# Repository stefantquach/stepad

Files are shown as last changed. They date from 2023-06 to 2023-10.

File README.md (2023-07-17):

# stepad

# Case notes:
Different material thicknesses (in stack order)
* plate thickness: White Delrin 0.06in (1.524mm)
* open1: White Acrylic 0.12in (3.05mm)
* open2: White Acrylic 0.18in (4.57mm)
* open3: White Acrylic 0.12in (3.05mm)
* bottom: White Acrylic 0.12in (3.05mm). This could be variable thickness and material.

# Build notes:
* Diode direction is reversed.

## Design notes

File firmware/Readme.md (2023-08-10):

# Stepad Firmware

### Notes:
* 1kHz interrupt for when ADC completes all samples and DMA transfer is complete. This needs to be larger than 4 samples for future use. Use DMA to trigger IRQ.
* During 1kHz interrupt, send keyboard report for the analog keys that were pressed during that poll.
* Maybe also include the digital keys in the 1kHz loop since they should be pretty fast.

* If DSP is needed, maybe have one CPU dedicated to sampling the ADC and then doing the DSP. Probably dont do this since this doesnt scale well with number of switches.

- USB HID report generator needs to be at user level. 
- CPU1 user level needs as light as possible.
- CPU1 User level runs at 1kHz delta timed loop.

- CPU1 ADC samples ADCS at n times the USB polling rate where n is the number of samples for debouncing

- CPU2 handles LED stuff

Switch 0: Top: 2036     Bottom:1513
Switch 1: Top: 2091     Bottom:1464
Switch 2: Top: 2012     Bottom:1311
Switch 3: Top: 2052     Bottom:1478

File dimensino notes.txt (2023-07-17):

14mm x 14mm hole
19.05

24.3

10mm from bottom plate to top of bottom case

PCB dimensions
35.05mm x 111.25mm

usb center to right edge: 55.675mm
usb center to left edge:  55.575mm

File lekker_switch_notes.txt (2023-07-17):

using AH49E hall sensor with VCC=3.3V

Sensor max voltage 2.3V @ 1000 G
Sensor min voltage 1.0V @ -1000 G

1.28V (bottom) to 1.56V (rest)
1.28V --> -569.231 Gauss
1.56V --> -138.462 Gauss

1.63 (rest) 1.31 (bottom)
1.31V --> -523.077 Gauss
1.63V --> -30.769 Gauss

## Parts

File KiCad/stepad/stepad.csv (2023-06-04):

Source: | C:\Users\stefa\Documents\Projects\stepad\KiCad\stepad\stepad.kicad_sch
Date: | 6/3/2023 11:15:48 AM
Tool: | Eeschema (6.0.0)
Generator: | C:\Users\stefa\Documents\Projects\stepad\KiCad\stepad\scripts/bom_generator.py
Component Count: | 69
Qnty | Product | Description | Value | Schematic | Note
16 | C0603C104M4RAC7411 | Unpolarized capacitor | 0.1u | C1, C2, C3, C4, C5, C10, C11, C12, C13, C14, C15, C16, C17, C18, C21, C24,
4 |  | Unpolarized capacitor | DNI | C6, C7, C8, C9,
2 | CL10B104KA8NNNC | Unpolarized capacitor | 1u | C19, C20,
2 | C0603C270J3GAC7867 | Unpolarized capacitor | 27p | C22, C23,
4 | QBLP677R-RGB | RGB LED, blue/green/red/anode | QBLP677R-RGB | D1, D2, D3, D4,
2 | 1N4148W-13-F | 75V 0.15A Fast Switching Diode, SOD-123 | 1N4148W | D5, D6,
1 | USB4105-GF-A |  | TYPE-C-31-M12_13_EDITED | J1,
1 |  | Generic connector, single row, 01x03, script generated (kicad-library-utils/schlib/autogen/connector/) | Conn_01x03 | J2,
2 |  |  | MX-NoLED | MX1, MX2,
4 | RC0603FR-070RL | Resistor, US symbol | 0 | R1, R2, R3, R4,
3 | RC0603JR-07300RL | Resistor, US symbol | 300 | R5, R6, R7,
2 | RC0603FR-1327RL | Resistor, US symbol | 27 | R8, R9,
3 |  | Resistor, US symbol | DNI | R10, R12, R13,
2 | RNCP0603FTD10K0 | Resistor, US symbol | 10k | R11, R16,
2 | RC0603FR-135K1L | Resistor, US symbol | 5.1k | R14, R15,
4 |  |  | MX_Lekker | SW1, SW2, SW3, SW4,
2 | MSLPT5252AG3TR | Push button switch, generic, two pins | SW_Push | SW5, SW6,
4 |  | test point | TestPoint | TP1, TP2, TP3, TP4,
4 | AH49ENTR-G1 |  | AH49-E | U1, U2, U3, U4,
1 | AZ1117IH-3.3TRG1 | 1A Low drop-out regulator, Fixed Output 3.3V, SOT-223 | NCP1117-3.3_SOT223 | U5,
1 | W25Q32JVSS | 32Mb Serial Flash Memory, Standard/Dual/Quad SPI, SOIC-8 | W25Q32JVSS | U6,
1 | SC0914(13) |  | RP2040 | U7,
1 | 82400102 | Low Capacitance TVS Diode Array, 2 Channels, SOT-23-6 | WE-TVS-82400102 | U8,
1 | RH100-12.000-18-2030-TR | Four pin crystal, GND on pins 2 and 4 | Crystal_GND24 | Y1,

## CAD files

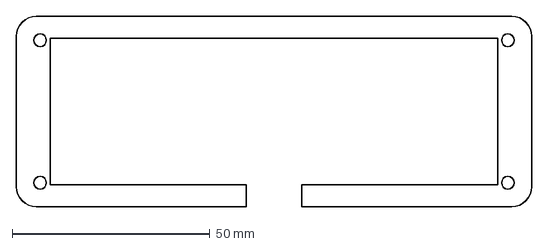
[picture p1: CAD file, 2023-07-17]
case/open2_1.dxf
130.3 x 48.1 mm

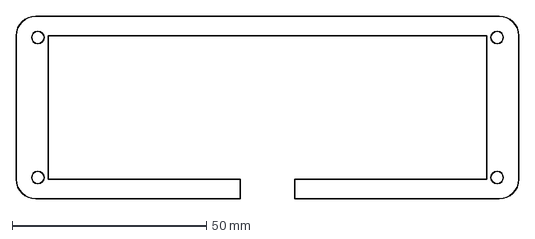
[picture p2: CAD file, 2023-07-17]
case/open2.dxf
129.3 x 47.0 mm

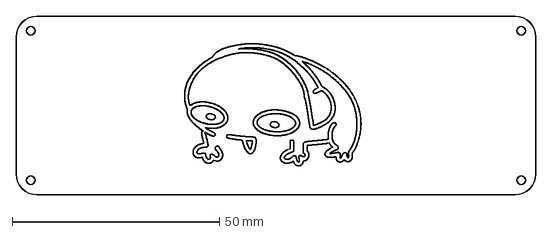
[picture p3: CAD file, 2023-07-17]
case/bottom.dxf
125.2 x 43.1 mm

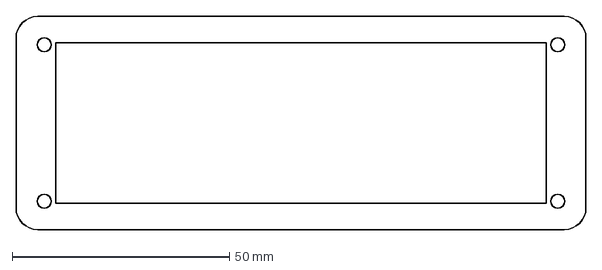
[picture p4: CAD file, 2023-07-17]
case/open3.dxf
131.2 x 49.1 mm

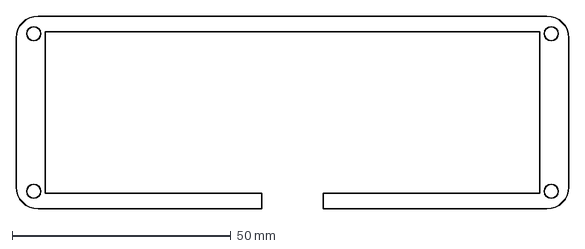
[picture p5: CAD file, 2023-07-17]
case/open1.dxf
126.3 x 44.1 mm

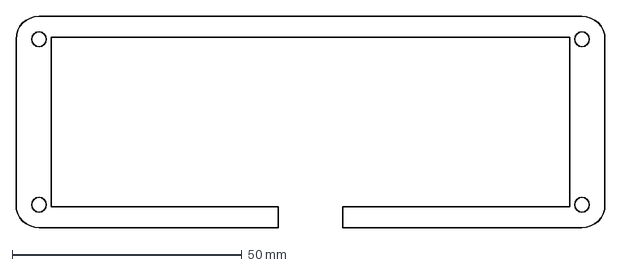
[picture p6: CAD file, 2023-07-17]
case/open1_2.dxf
128.3 x 46.1 mm

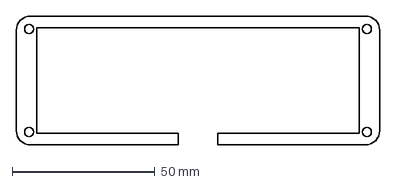
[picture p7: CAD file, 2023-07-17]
case/open1_1.dxf
127.3 x 45.0 mm

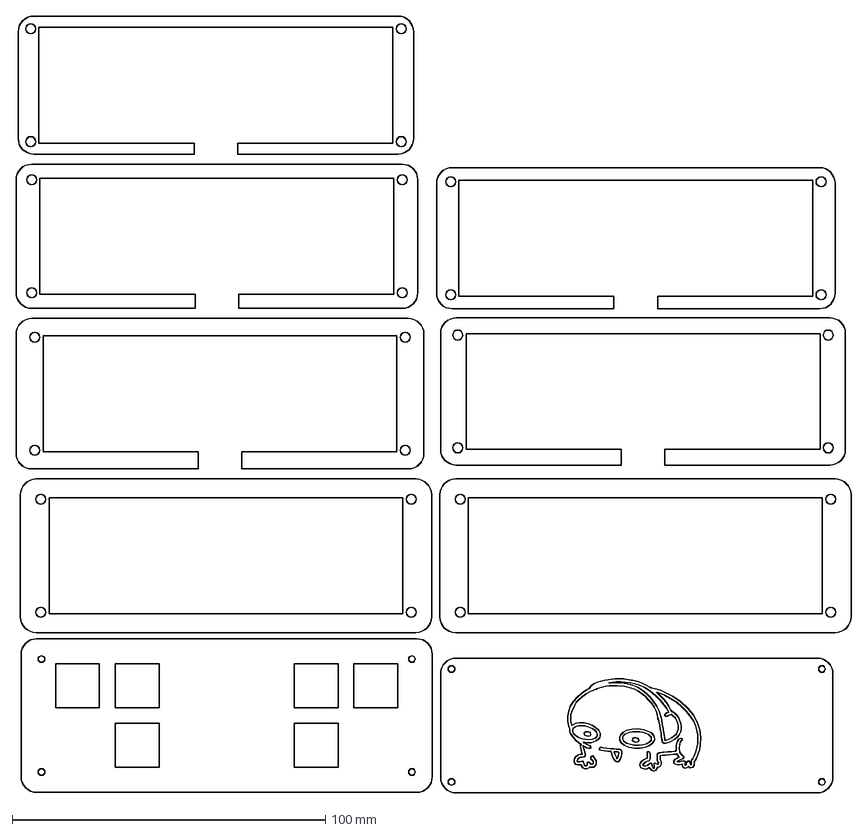
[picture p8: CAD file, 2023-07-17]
case/combined3.dxf
266.6 x 248.0 mm

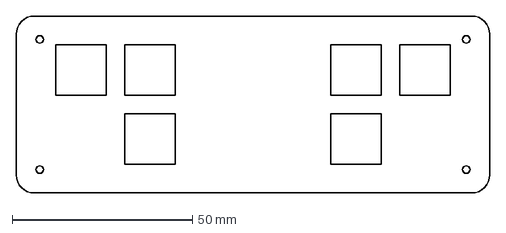
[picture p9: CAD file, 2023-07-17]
case/plate.dxf
131.2 x 49.1 mm

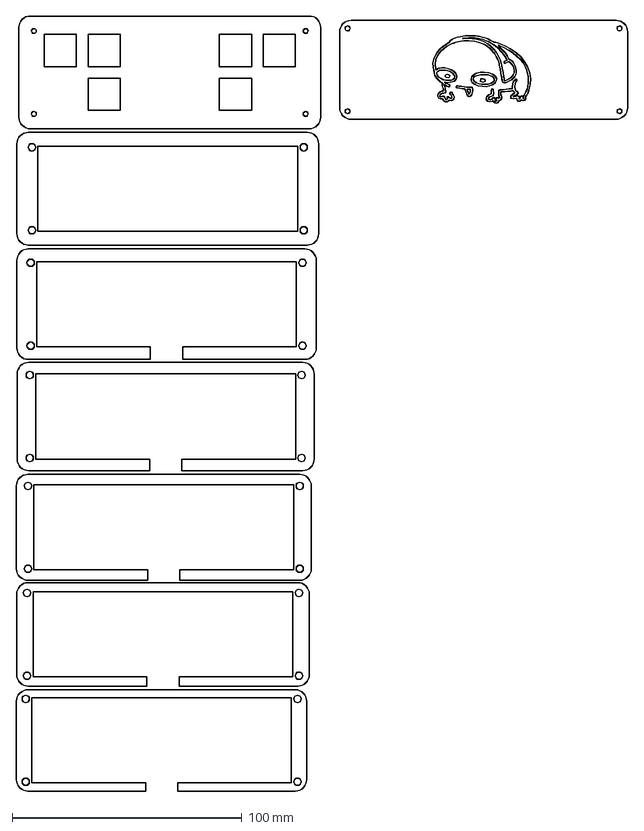
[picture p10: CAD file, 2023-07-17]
case/combined2.dxf
265.8 x 337.1 mm

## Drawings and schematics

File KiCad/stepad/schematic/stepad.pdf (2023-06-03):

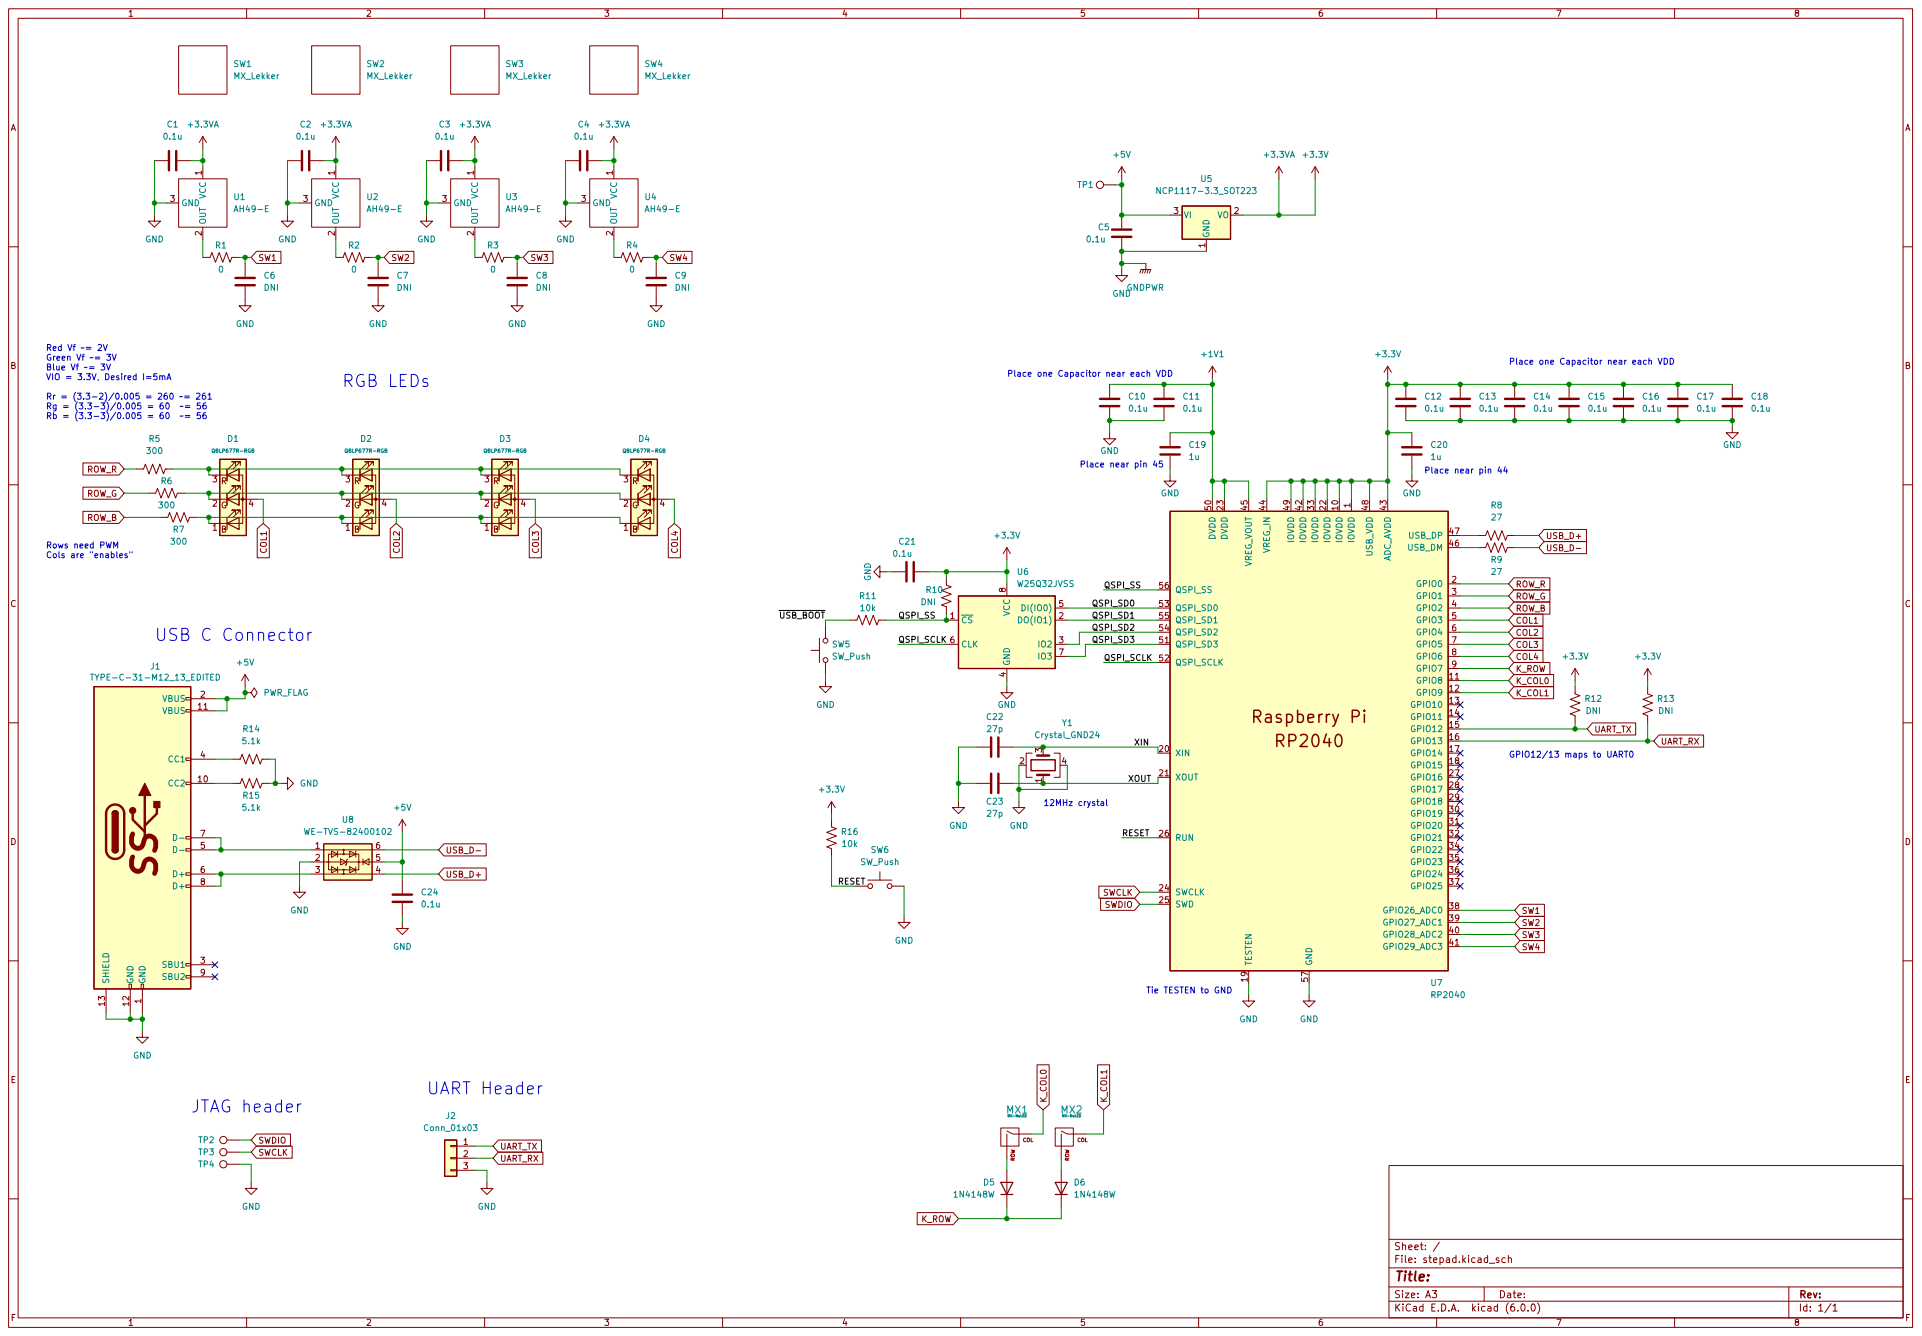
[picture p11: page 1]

2 GND 3 U4AH49-E GND GND SS GND

Cols are "enables" Red Vf ~= 2V Green Vf ~= 3V

Place one Capacitor near each VDD

1 IOVDD 10 GPIO8 11 GPIO9 12 GPIO10 13 GPIO11 14 GPIO12 15 GPIO13 16 GPIO14 17 GPIO15 18 TESTEN 19 GPIO0 2 XIN 20 XOUT 21 IOVDD 22 DVDD 23 SWCLK 24 SWD 25 RUN 26 GPIO16 27 GPIO17 28 GPIO18 29 GPIO1 3 GPIO19 30 GPIO20 31 GPIO21 32 IOVDD 33 GPIO22 34 GPIO23 35 GPIO24 36 GPIO25 37 GPIO26_ADC0 38 GPIO27_ADC1 39 GPIO2 4 GPIO28_ADC2 40 GPIO29_ADC3 41 IOVDD 42 ADC_AVDD 43 VREG_IN 44 VREG_VOUT 45 USB_DM 46 USB_DP 47 USB_VDD 48 IOVDD 49 GPIO3 5 DVDD 50 QSPI_SD3 51 QSPI_SCLK 52 QSPI_SD0 53 QSPI_SD2 54 QSPI_SD1 55 QSPI_SS 56 GND 57 GPIO4 6 GPIO5 7 GPIO6 8 GPIO7 9 U7RP2040

GPIO12/13 maps to UART0 Rows need PWM

1 CC2 10 VBUS 11 GND 12 SHIELD 13 VBUS 2 SBU1 3 CC1 4 D- 5 D+ 6 D- 7 D+ 8 SBU2 9

Tie TESTEN to GND UART Header

COL ROW MX1 MX-NoLED

COL ROW MX2 MX-NoLED

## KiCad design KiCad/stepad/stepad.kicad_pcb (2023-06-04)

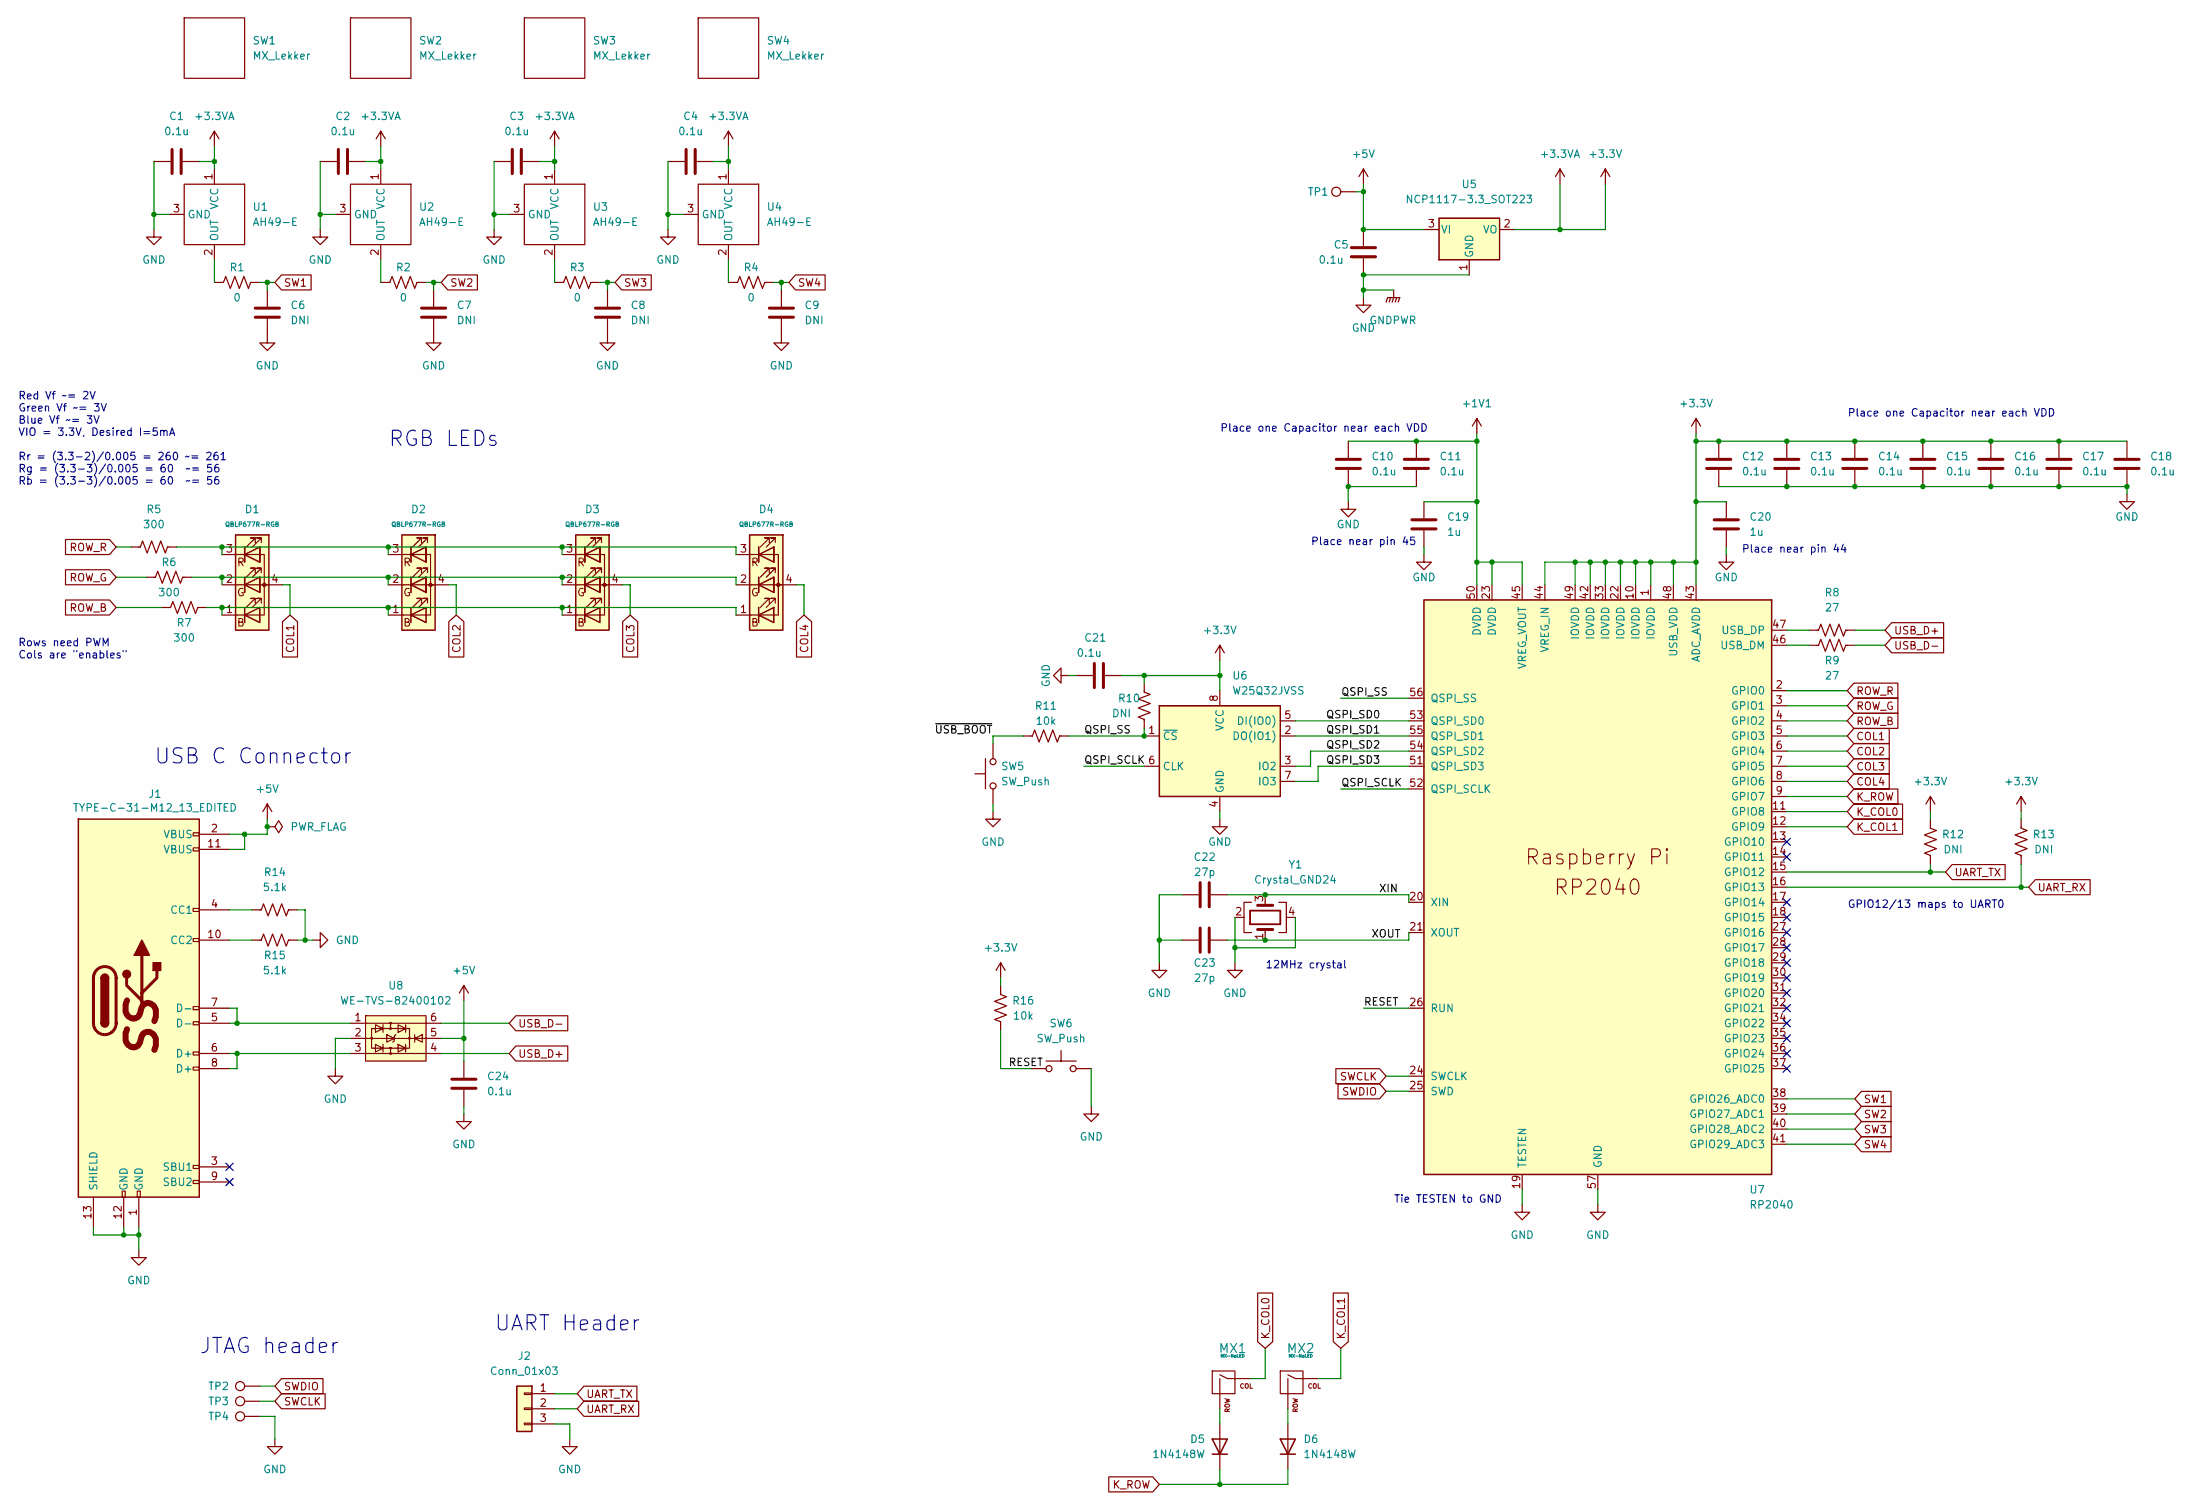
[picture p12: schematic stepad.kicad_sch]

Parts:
C1, C2, C3, C4, C5, C10, C11, C12, C13, C14, C15, C16, C17, C18, C21, C24: 0.1u; C_0603_1608Metric_Pad1.08x0.95mm_HandSolder; Part Number C0603C104M4RAC7411
C6, C7, C8, C9: DNI; C_0603_1608Metric_Pad1.08x0.95mm_HandSolder
C19, C20: 1u; C_0603_1608Metric_Pad1.08x0.95mm_HandSolder; Part Number CL10B104KA8NNNC
C22, C23: 27p; C_0603_1608Metric_Pad1.08x0.95mm_HandSolder; Part Number C0603C270J3GAC7867
D1, D2, D3, D4: QBLP677R-RGB; QBLP677R-RGB-square_cutout; Part Number QBLP677R-RGB
D5, D6: 1N4148W; D_SOD-123; Part Number 1N4148W-13-F
J1: TYPE-C-31-M12_13_EDITED; HRO-TYPE-C-31-M-12-HandSoldering; Part Number USB4105-GF-A
J2: Conn_01x03; PinHeader_1x03_P2.54mm_Vertical
MX1, MX2: MX-NoLED; MX-Hotswap-1U
R1, R2, R3, R4: 0; R_0603_1608Metric_Pad0.98x0.95mm_HandSolder; Part Number RC0603FR-070RL
R5, R6, R7: 300; R_0603_1608Metric_Pad0.98x0.95mm_HandSolder; Part Number RC0603JR-07300RL
R8, R9: 27; R_0603_1608Metric_Pad0.98x0.95mm_HandSolder; Part Number RC0603FR-1327RL
R10, R12, R13: DNI; R_0603_1608Metric_Pad0.98x0.95mm_HandSolder
R11, R16: 10k; R_0603_1608Metric_Pad0.98x0.95mm_HandSolder; Part Number RNCP0603FTD10K0
R14, R15: 5.1k; R_0603_1608Metric_Pad0.98x0.95mm_HandSolder; Part Number RC0603FR-135K1L
SW1, SW2, SW3, SW4: MX_Lekker
SW5, SW6: SW_Push; SKQG-1155865; Part Number MSLPT5252AG3TR
TP1, TP2, TP3, TP4: TestPoint; TestPoint_Pad_1.5x1.5mm
U1, U2, U3, U4: AH49-E; SOT-23_Handsoldering_no_plane; Part Number AH49ENTR-G1
U5: NCP1117-3.3_SOT223; SOT-223-3_TabPin2; Part Number AZ1117IH-3.3TRG1
U6: W25Q32JVSS; SOIC-8_5.23x5.23mm_P1.27mm; Part Number W25Q32JVSS
U7: RP2040; RP2040-QFN-56; Part Number SC0914(13)
U8: WE-TVS-82400102; SOT-23-6; Part Number 82400102
Y1: Crystal_GND24; Crystal_SMD_3225-4Pin_3.2x2.5mm; Part Number RH100-12.000-18-2030-TR

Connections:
+1V1: C10.1, C11.1, C19.1, U7.23 (DVDD), U7.45 (VREG_VOUT), U7.50 (DVDD)
+3.3VA: C1.1, C2.1, C3.1, C4.1, C12.1, C13.1, C14.1, C15.1, C16.1, C17.1, C18.1, C20.1, C21.2, R10.2, R12.1, R13.1, R16.1, U1.1 (VCC), U2.1 (VCC), U3.1 (VCC), U4.1 (VCC), U5.2 (VO), U6.8 (VCC), U7.1 (IOVDD), U7.10 (IOVDD), U7.22 (IOVDD), U7.33 (IOVDD), U7.42 (IOVDD), U7.43 (ADC_AVDD), U7.44 (VREG_IN), U7.48 (USB_VDD), U7.49 (IOVDD)
+5V: C5.2, C24.1, J1.2 (VBUS), J1.11 (VBUS), TP1.1, U5.3 (VI), U8.5
/QSPI_SCLK: U6.6 (CLK), U7.52 (QSPI_SCLK)
/QSPI_SD0: U6.5 (DI(IO0)), U7.53 (QSPI_SD0)
/QSPI_SD1: U6.2 (DO(IO1)), U7.55 (QSPI_SD1)
/QSPI_SD2: U6.3 (IO2), U7.54 (QSPI_SD2)
/QSPI_SD3: U6.7 (IO3), U7.51 (QSPI_SD3)
/QSPI_SS: R10.1, R11.2, U6.1 (~CS), U7.56 (QSPI_SS)
/RESET: R16.2, SW6.1, SW6.3, U7.26 (RUN)
/XIN: C22.2, U7.20 (XIN), Y1.3
/XOUT: C23.2, U7.21 (XOUT), Y1.1
/~USB_BOOT: R11.1, SW5.2
COL1: D1.4 (A), U7.5 (GPIO3)
COL2: D2.4 (A), U7.6 (GPIO4)
COL3: D3.4 (A), U7.7 (GPIO5)
COL4: D4.4 (A), U7.8 (GPIO6)
GND: C1.2, C2.2, C3.2, C4.2, C5.1, C6.2, C7.2, C8.2, C9.2, C10.2, C11.2, C12.2, C13.2, C14.2, C15.2, C16.2, C17.2, C18.2, C19.2, C20.2, C21.1, C22.1, C23.1, C24.2, J1.1 (GND), J1.12 (GND), J1.13 (SHIELD), J2.3, R14.2, R15.1, SW5.1, SW6.2, SW6.4, TP4.1, U1.3 (GND), U2.3 (GND), U3.3 (GND), U4.3 (GND), U5.1 (GND), U6.4 (GND), U7.19 (TESTEN), U7.57 (GND), U8.2, Y1.2, Y1.4
K_COL0: MX1.1 (COL), U7.11 (GPIO8)
K_COL1: MX2.1 (COL), U7.12 (GPIO9)
K_ROW: D5.1 (K), D6.1 (K), U7.9 (GPIO7)
unnamed: D1.1 (BK), D2.1 (BK), D3.1 (BK), D4.1 (BK), R7.1
unnamed: D1.2 (GK), D2.2 (GK), D3.2 (GK), D4.2 (GK), R6.2
unnamed: D1.3 (RK), D2.3 (RK), D3.3 (RK), D4.3 (RK), R5.2
unnamed: D5.2 (A), MX1.2 (ROW)
unnamed: D6.2 (A), MX2.2 (ROW)
unnamed: J1.4 (CC1), R14.1
unnamed: J1.5 (D-), J1.7 (D-), U8.1
unnamed: J1.6 (D+), J1.8 (D+), U8.3
unnamed: J1.10 (CC2), R15.2
unnamed: R1.1, U1.2 (OUT)
unnamed: R2.1, U2.2 (OUT)
unnamed: R3.1, U3.2 (OUT)
unnamed: R4.1, U4.2 (OUT)
unnamed: R8.1, U7.47 (USB_DP)
unnamed: R9.2, U7.46 (USB_DM)
ROW_B: R7.2, U7.4 (GPIO2)
ROW_G: R6.1, U7.3 (GPIO1)
ROW_R: R5.1, U7.2 (GPIO0)
SW1: C6.1, R1.2, U7.38 (GPIO26_ADC0)
SW2: C7.1, R2.2, U7.39 (GPIO27_ADC1)
SW3: C8.1, R3.2, U7.40 (GPIO28_ADC2)
SW4: C9.1, R4.2, U7.41 (GPIO29_ADC3)
SWCLK: TP3.1, U7.24 (SWCLK)
SWDIO: TP2.1, U7.25 (SWD)
UART_RX: J2.2, R13.2, U7.16 (GPIO13)
UART_TX: J2.1, R12.2, U7.15 (GPIO12)
USB_D+: R8.2, U8.4
USB_D-: R9.1, U8.6

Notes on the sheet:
Place near pin 44
Rows need PWM Cols are "enables"
USB C Connector
JTAG header
Place one Capacitor near each VDD
RGB LEDs
UART Header
Red Vf ~= 2V Green Vf ~= 3V Blue Vf ~= 3V VIO = 3.3V, Desired I=5mA Rr = (3.3-2)/0.005 = 260 ~= 261 Rg = (3.3-3)/0.005 = 60 ~= 56 Rb = (3.3-3)/0.005 = 60 ~= 56
12MHz crystal
Place near pin 45
Tie TESTEN to GND
GPIO12/13 maps to UART0

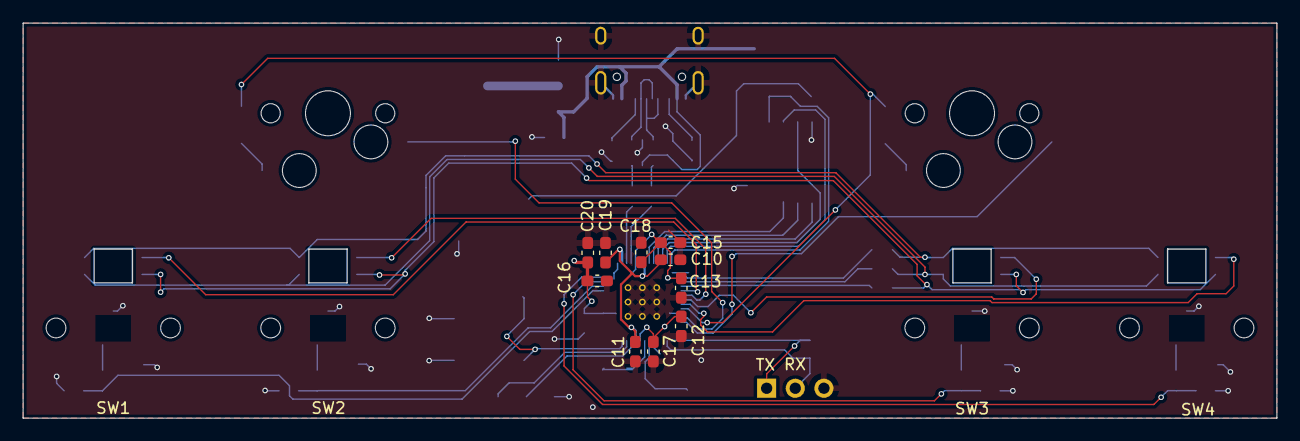
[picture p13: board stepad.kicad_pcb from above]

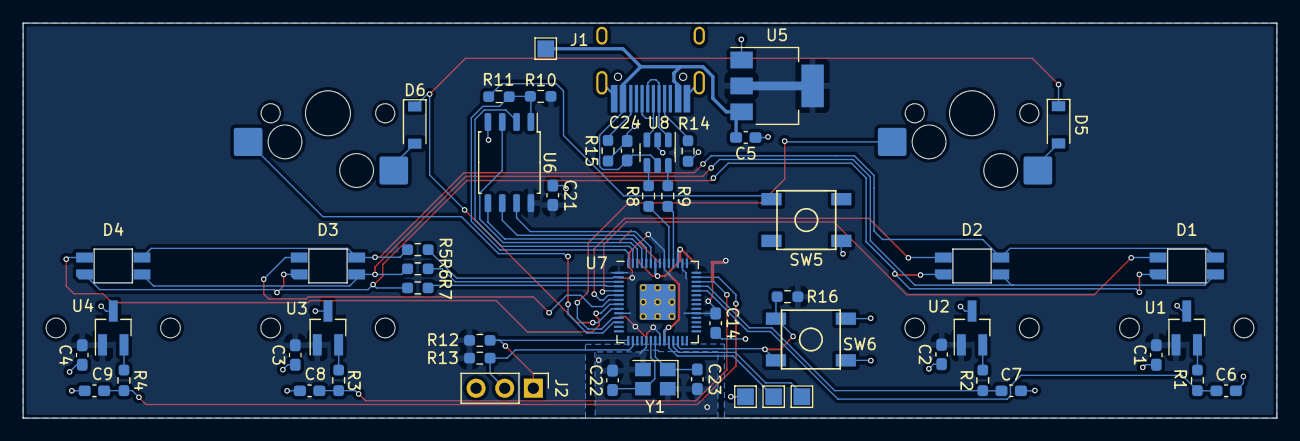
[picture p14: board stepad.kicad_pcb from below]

Board: 2 copper layers, 111.2 x 35.0 mm, 69 parts (53 on the bottom side), 49 nets.

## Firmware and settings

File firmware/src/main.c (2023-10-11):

/**
 * Copyright (c) 2020 Raspberry Pi (Trading) Ltd.
 *
 * SPDX-License-Identifier: BSD-3-Clause
 */
#include <stdio.h>
#include "pico/stdlib.h"
#include "pico/bootrom.h"
#include "pico/multicore.h"
#include "hardware/adc.h"
#include "hardware/dma.h"
#include "lekker_switch.h"
#include "digital_switch.h"
#include "led_matrix.h"
#include "led_effects.h"
#include "console.h"
#include "settings.h"
#include "parameters.h"
#include "keymap.h"

#include "bsp/board.h"
#include "tusb.h"

/**
 * Helper function to check if bootloader needs to be entered.
 * The desired behavior is to check this once after a reset.
*/
void check_for_boot()
{
    // Initialize one of the keyswitches so we can tell if we need to go into the bootloader
    gpio_init(STEPAD_K_ROW);
    gpio_set_dir(STEPAD_K_ROW, GPIO_OUT);
    gpio_init(STEPAD_K_COL0);
    gpio_init(STEPAD_K_COL1);
    gpio_set_dir(STEPAD_K_COL0, GPIO_IN);
    gpio_pull_down(STEPAD_K_COL0); // Enable pulldown resistor.
    gpio_set_dir(STEPAD_K_COL1, GPIO_IN);
    gpio_pull_down(STEPAD_K_COL1); // Enable pulldown resistor.

    // Check if Switch is pressed (COL0 is high). If so enter bootloader
    gpio_put(STEPAD_K_ROW, 1);
    for(volatile int i=0; i<2000; ++i)
        ; // wait a bit for the pin level to rise
    if(gpio_get(STEPAD_K_COL0))
    {
        // If one button is pressed on startup, enter bootloader mode
        reset_usb_boot(0, 0);
    }
    if(gpio_get(STEPAD_K_COL1))
    {
        // If the other button is pressed, enable debug console
        debug_console_enable = true;
    }
}

/**
 * CPU1 Entry
*/
void core1_main() {

    // Need to allow cores to be locked in the case flash needs to be written to
    multicore_lockout_victim_init();

    // initialize LED matrix
    initialize_led_pwms();

    start_led_process();
    
    // printf("Starting CPU1 loop\n");
    absolute_time_t start_time_10Hz = get_absolute_time();
    while(1)
    {
        // tight_loop_contents();
        // 10 Hz loop
        absolute_time_t finish_time = get_absolute_time();
        uint64_t time_diff_us = absolute_time_diff_us(start_time_10Hz, finish_time);
        if(time_diff_us > 100000ULL)
        {
            start_time_10Hz = finish_time;
            
            hue_travel();
        }
    }
}

/**
 * CPU0 Entry
*/
int main() {
    stdio_uart_init();

    // Check for boot mode
    // This check is only performed on start up.
    check_for_boot();

    // Need to allow cores to be locked in the case flash needs to be written to
    multicore_lockout_victim_init();

    // Need to initialize this before CPU2 starts since this reads from flash
    initialize_settings();

    // Initialize CPU2
    multicore_launch_core1(core1_main);

    // Initialize TinyUSB
    board_init();
    tusb_init();

    if(debug_console_enable)
    {
        stdio_usb_init();
    }
    
    // Initialize processes
    init_switch_adc();
    init_digital_switches();
    console_initialize();

    // Start ADCs
    start_switch_adc();

    printf("Starting CPU0 loop\n");
    while(1)
    {
        console_process();

        tud_task();
    }

}

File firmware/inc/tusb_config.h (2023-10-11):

/*
 * The MIT License (MIT)
 *
 * Copyright (c) 2019 Ha Thach (tinyusb.org)
 *
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
 */

#ifndef _TUSB_CONFIG_H_
#define _TUSB_CONFIG_H_

#ifdef __cplusplus
 extern "C" {
#endif

//--------------------------------------------------------------------
// COMMON CONFIGURATION
//--------------------------------------------------------------------

// defined by board.mk
#ifndef CFG_TUSB_MCU
  #error CFG_TUSB_MCU must be defined
#endif

// RHPort number used for device can be defined by board.mk, default to port 0
#ifndef BOARD_DEVICE_RHPORT_NUM
  #define BOARD_DEVICE_RHPORT_NUM     0
#endif

// RHPort max operational speed can defined by board.mk
// Default to Highspeed for MCU with internal HighSpeed PHY (can be port specific), otherwise FullSpeed
#ifndef BOARD_DEVICE_RHPORT_SPEED
  #if (CFG_TUSB_MCU == OPT_MCU_LPC18XX || CFG_TUSB_MCU == OPT_MCU_LPC43XX || CFG_TUSB_MCU == OPT_MCU_MIMXRT10XX || \
       CFG_TUSB_MCU == OPT_MCU_NUC505  || CFG_TUSB_MCU == OPT_MCU_CXD56 || CFG_TUSB_MCU == OPT_MCU_SAMX7X)
    #define BOARD_DEVICE_RHPORT_SPEED   OPT_MODE_HIGH_SPEED
  #else
    #define BOARD_DEVICE_RHPORT_SPEED   OPT_MODE_FULL_SPEED
  #endif
#endif

// Device mode with rhport and speed defined by board.mk
#if   BOARD_DEVICE_RHPORT_NUM == 0
  #define CFG_TUSB_RHPORT0_MODE     (OPT_MODE_DEVICE | BOARD_DEVICE_RHPORT_SPEED)
#elif BOARD_DEVICE_RHPORT_NUM == 1
  #define CFG_TUSB_RHPORT1_MODE     (OPT_MODE_DEVICE | BOARD_DEVICE_RHPORT_SPEED)
#else
  #error "Incorrect RHPort configuration"
#endif

#ifndef CFG_TUSB_OS
#define CFG_TUSB_OS               OPT_OS_NONE
#endif

// CFG_TUSB_DEBUG is defined by compiler in DEBUG build
// #define CFG_TUSB_DEBUG           0

/* USB DMA on some MCUs can only access a specific SRAM region with restriction on alignment.
 * Tinyusb use follows macros to declare transferring memory so that they can be put
 * into those specific section.
 * e.g
 * - CFG_TUSB_MEM SECTION : __attribute__ (( section(".usb_ram") ))
 * - CFG_TUSB_MEM_ALIGN   : __attribute__ ((aligned(4)))
 */
#ifndef CFG_TUSB_MEM_SECTION
#define CFG_TUSB_MEM_SECTION
#endif

#ifndef CFG_TUSB_MEM_ALIGN
#define CFG_TUSB_MEM_ALIGN          __attribute__ ((aligned(4)))
#endif

//--------------------------------------------------------------------
// DEVICE CONFIGURATION
//--------------------------------------------------------------------

#ifndef CFG_TUD_ENDPOINT0_SIZE
#define CFG_TUD_ENDPOINT0_SIZE    64
#endif

//------------- CLASS -------------//
#define CFG_TUD_HID               2
#define CFG_TUD_CDC               1
#define CFG_TUD_MSC               0
#define CFG_TUD_MIDI              0
#define CFG_TUD_VENDOR            0

// HID buffer size Should be sufficient to hold ID (if any) + Data
#define CFG_TUD_HID_EP_BUFSIZE    64

// CDC buffer for USB Debug console
#define CFG_TUD_CDC_EP_BUFSIZE    64

// CDC FIFO size of TX and RX
#define CFG_TUD_CDC_RX_BUFSIZE   (256)
#define CFG_TUD_CDC_TX_BUFSIZE   (256)

#ifdef __cplusplus
 }
#endif

#endif /* _TUSB_CONFIG_H_ */

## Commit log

2023-05-28 initial design
    [stepad.kicad_pcb, stepad.kicad_sch]
2023-06-03 Finished initial layout
    [stepad.kicad_pcb]
2023-06-03 Adding part numbers and updating some footprints
    [stepad-B_Cu.gbl, stepad-B_Mask.gbs, stepad-B_Paste.gbp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]
2023-06-03 Updating part numbers and gerber files
    [stepad-B_Cu.gbl, stepad-B_Mask.gbs, stepad-B_Paste.gbp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]
2023-06-04 Updating gerbers and adding firmware folder
    [stepad-B_Cu.gbl, stepad-B_Mask.gbs, stepad-B_Paste.gbp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]
2023-07-17 Adding case DXF files. Firmware WIP, LED matrix now works
    [bottom.dxf, combined2.dxf, combined3.dxf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]
2023-07-23 Added firmware for LED matrix and engineering console for calibration procedure
2023-08-10 Added digital switches and basic USB keyboard functionality. WIP keymap, WIP settings, WIP rapid trigger
2023-10-08 Adding version.h header file and add NACK if switch threshold is too small
    [lekker_switch.c]
2023-10-15 Add rapid trigger sensitivity to settings report. Prevent switches running while calibration in progress
    [console.c, lekker_switch.c]
